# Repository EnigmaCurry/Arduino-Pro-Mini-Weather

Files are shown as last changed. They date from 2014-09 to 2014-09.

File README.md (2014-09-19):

Arduino Pro-Mini Enviromental Display Project
========================

This is an arduino project to build a miniature environment sensor
module to display temperature, barometric pressure, and humidity.

All files contained herein produced by
[R&TPreppers](https://www.youtube.com/channel/UCTNV_Oh5QAi1Is9r9Aw5bpw)
/ [njsharkracer](https://github.com/njsharkracer)

Arduino Pro Mini Weather Video (https://www.youtube.com/watch?v=pLE4Hpk1XHw)

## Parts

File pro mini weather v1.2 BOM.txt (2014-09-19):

| BT1        1.5V AA     AA Battery Holder
| C1         47uF        1210
| C2         10uF        0805
| C3         100nF       0805
| D1         DIODESCH    SOD-123
| L1         68uH        0805
| R1         4.7K        0805
| R2         4.7K        0805
| U1         NCP1402     SOT23-5
| U2         PRO_MINI    Sparkfun pro mini 5V 16Mhz
| U3         DHT22       Through Hole
| U4         BMP180      Custom Footprint
| U5         NOKIA_5110  Through Hole

If you want to order the boards directly through OSHPark:

https://oshpark.com/profiles/rtpreppers

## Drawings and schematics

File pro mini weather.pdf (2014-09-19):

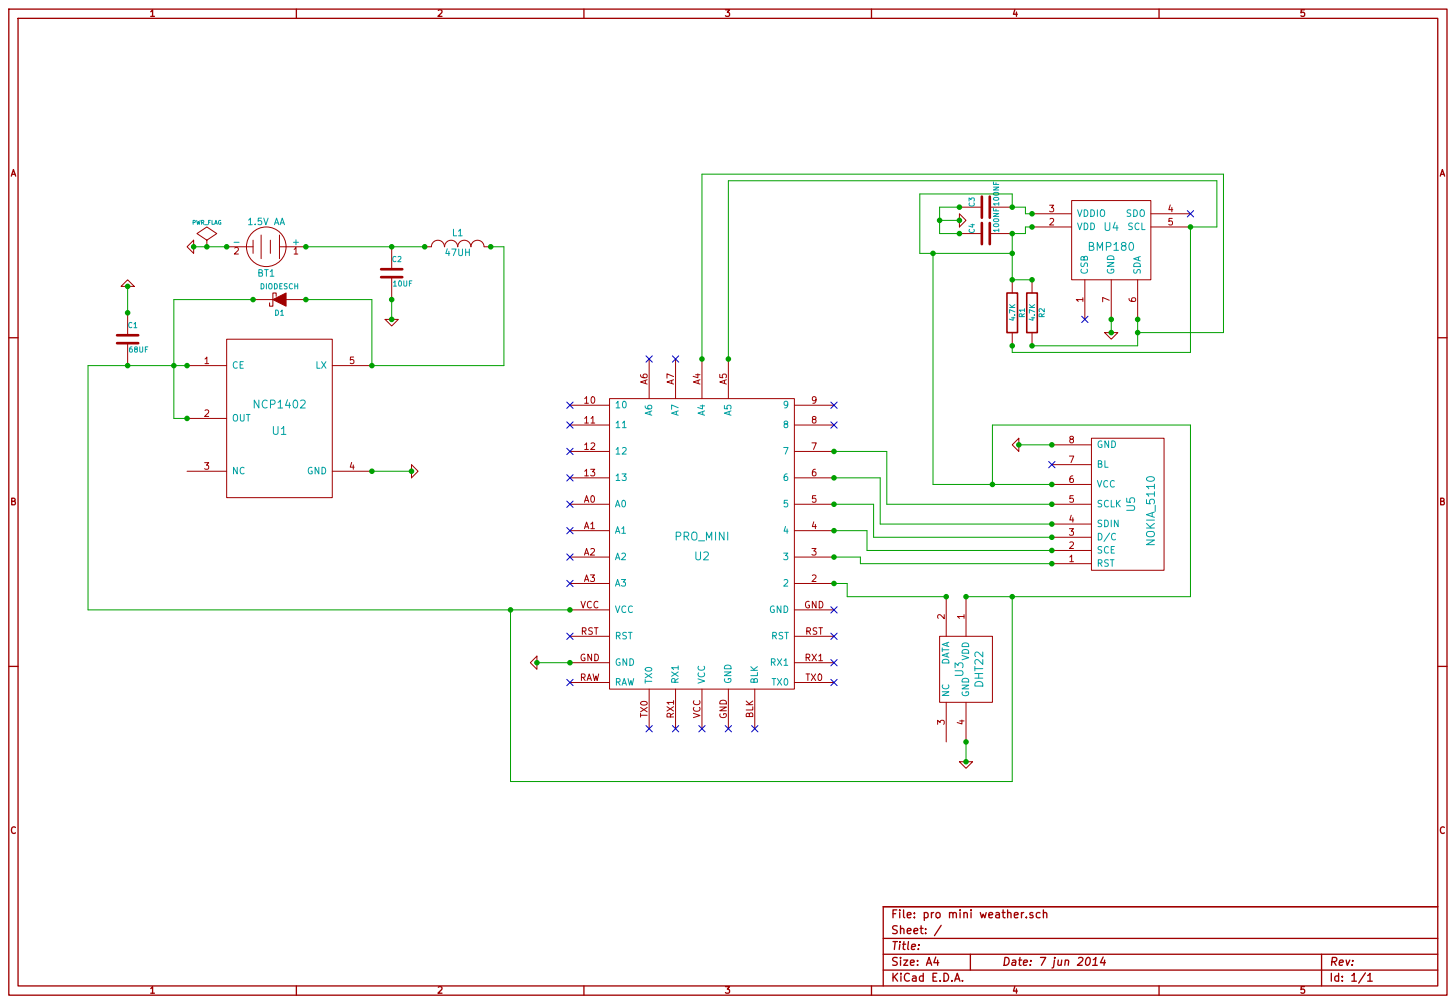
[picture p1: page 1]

Id: 1/1 Title: File: pro mini weather.sch

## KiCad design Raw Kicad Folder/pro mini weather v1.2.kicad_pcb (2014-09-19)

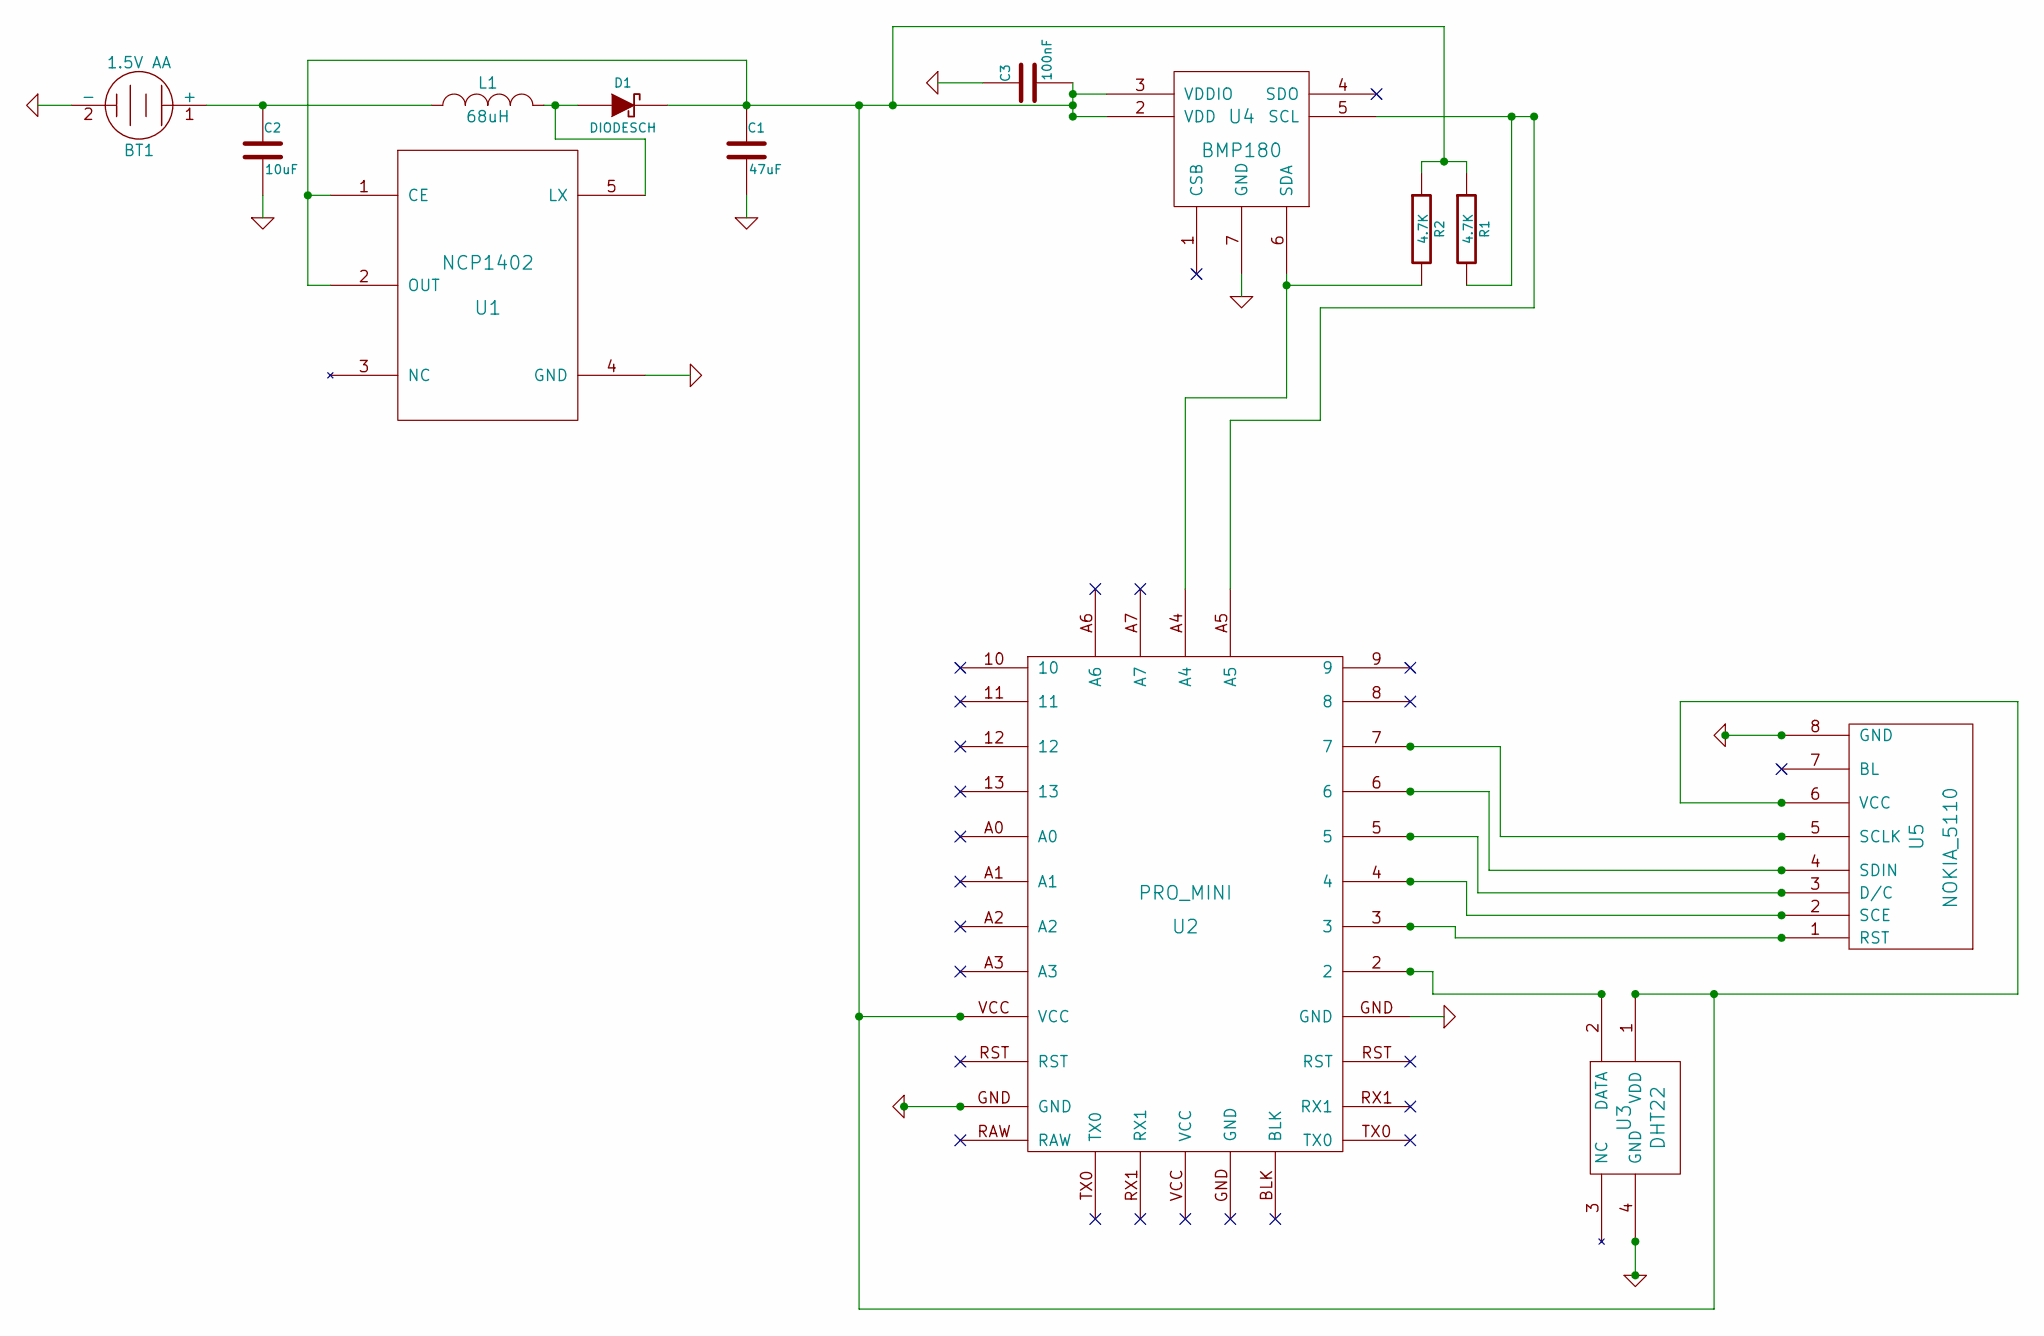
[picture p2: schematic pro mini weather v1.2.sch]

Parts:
BT1: 1.5V AA
C1: 47uF
C2: 10uF
C3: 100nF
D1: DIODESCH
L1: 68uH
R1, R2: 4.7K
U1: NCP1402
U2: PRO_MINI
U3: DHT22
U4: BMP180
U5: NOKIA_5110

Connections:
GND: BT1.2 (-), C1.2, C2.2, C3.1, U1.4 (GND), U2.GND, U3.4 (GND), U4.7 (GND), U5.8 (GND)
unnamed: D1.1 (A), L1.2, U1.5 (LX)
unnamed: R2.2, U2.A4, U4.6 (SDA)
unnamed: R1.2, U2.A5, U4.5 (SCL)
unnamed: C1.1, C3.2, D1.2 (K), R1.1, R2.1, U1.1 (CE), U1.2 (OUT), U2.VCC, U3.1 (VDD), U4.2 (VDD), U4.3 (VDDIO), U5.6 (VCC)
unnamed: U2.2, U3.2 (DATA)
unnamed: U2.3, U5.1 (RST)
unnamed: U2.5, U5.3 (D/C)
unnamed: U2.6, U5.4 (SDIN)
unnamed: U2.7, U5.5 (SCLK)
unnamed: U2.4, U5.2 (SCE)
unnamed: BT1.1 (+), C2.1, L1.1

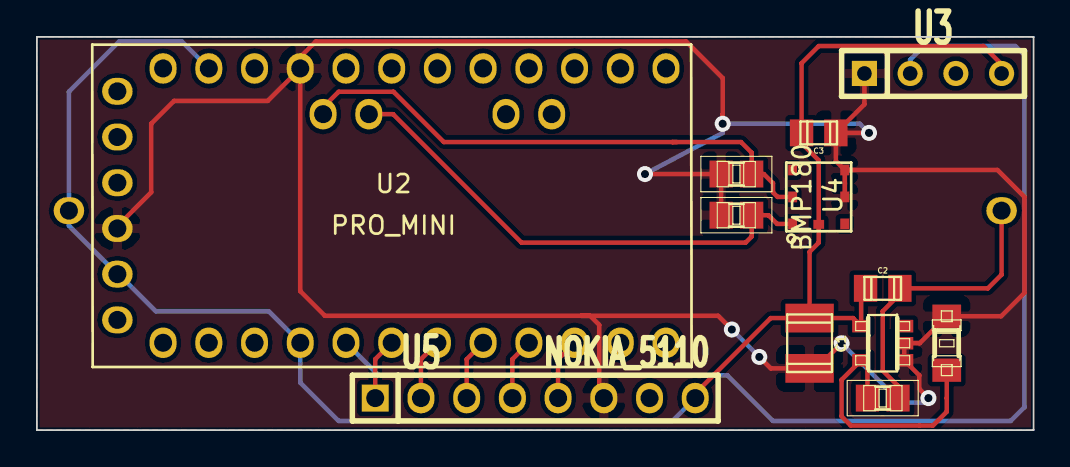
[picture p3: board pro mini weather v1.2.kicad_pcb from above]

Board: 2 copper layers, 55.4 x 21.8 mm, 13 parts (1 on the bottom side), 12 nets.

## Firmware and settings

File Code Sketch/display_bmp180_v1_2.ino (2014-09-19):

#include <SPI.h>
#include "Adafruit_GFX.h"
#include "Adafruit_PCD8544.h"
#include <SFE_BMP180.h>
#include <Wire.h>
#include "LowPower.h"
#include "DHT.h"
 
//GFX, DHT & PCD8544 can be found in adafruits github.
//SFE_BMP180 can be found on Sparkfun's github.


// Software SPI (slower updates, more flexible pin options):
// pin 7 - Serial clock out (SCLK)
// pin 6 - Serial data out (DIN)
// pin 5 - Data/Command select (D/C)
// pin 4 - LCD chip select (CS)
// pin 3 - LCD reset (RST)
Adafruit_PCD8544 display = Adafruit_PCD8544(7, 6, 5, 4, 3);

SFE_BMP180 pressure;

//#define ALTITUDE 15.0 //  Altitude at location
#define DHTPIN 2
#define DHTTYPE DHT22

DHT dht(DHTPIN, DHTTYPE);

void setup()   
{

Serial.begin(9600);

  // Initalize the BMP180 Sensor
  if (pressure.begin())

    dht.begin();
    display.begin();
  // init done

  // you can change the contrast around to adapt the display
  // for the best viewing!
  display.setContrast(57);
  display.clearDisplay();   // clears the screen and buffer

}


void loop() {

  // Reading temperature or humidity takes about 250 milliseconds!
  // Sensor readings may also be up to 2 seconds 'old' (its a very slow sensor)
  int h = dht.readHumidity();
  // Read temperature as Celsius
  int t = dht.readTemperature();
  // Read temperature as Fahrenheit
  int f = dht.readTemperature(true);
  
  // Compute heat index
  // Must send in temp in Fahrenheit!
  int hi = dht.computeHeatIndex(f, h);

  
  //  Display Names On Left Side Of Display And Horizontal Lines
  display.clearDisplay();
  display.setTextSize(1);
  display.setCursor(0,0);
  display.print("T");
  display.setCursor(6,3);
  display.print("E");
  display.setCursor(12,5);
  display.print("M");
  display.setCursor(18,7);
  display.print("P");
  display.setCursor(0,18);
  display.print("P");
  display.setCursor(6,20);
  display.print("R");
  display.setCursor(12,22);
  display.print("E");
  display.setCursor(18,24);
  display.print("S");
  display.setCursor(0,35);
  display.print("H");
  display.setCursor(7,37);
  display.print("U");
  display.setCursor(14,39);
  display.print("M");
  display.drawLine(0,15,84,15,1);
  display.drawLine(0,32,84,32,1);

  
  char status;
  double T,P,p0,a;

  // Loop here getting pressure readings every 10 seconds.
  // Start a temperature measurement:
  // If request is successful, the number of ms to wait is returned.
  // If request is unsuccessful, 0 is returned.

  status = pressure.startTemperature();
  if (status != 0)
  {
    // Wait for the measurement to complete:
    delay(status);

    // Retrieve the completed temperature measurement:
    // Note that the measurement is stored in the variable T.
    // Function returns 1 if successful, 0 if failure.

    status = pressure.getTemperature(T);
    if (status != 0)
    {

      // Print out the measurement:
      display.setCursor(24,0);
      display.setTextSize(2);
      display.print((9.0/5.0)*T+32.0,0);
      display.print("'F");

      // Start a pressure measurement:
      // The parameter is the oversampling setting, from 0 to 3 (highest res, longest wait).
      // If request is successful, the number of ms to wait is returned.
      // If request is unsuccessful, 0 is returned.

      status = pressure.startPressure(3);
      if (status != 0)
      {
        // Wait for the measurement to complete:
        delay(status);

        // Retrieve the completed pressure measurement:
        // Note that the measurement is stored in the variable P.
        // Note also that the function requires the previous temperature measurement (T).
        // (If temperature is stable, you can do one temperature measurement for a number of pressure measurements.)
        // Function returns 1 if successful, 0 if failure.

        status = pressure.getPressure(P,T);
        if (status != 0)
        {
          // Print out the measurement:
          display.setCursor(24,17);
          display.print(P*0.0295333727,2);
          display.setCursor(24,34); 
          display.print(h+2);
          display.print("%");
          display.setTextSize(1);
          display.setCursor(60,34);
          display.print("H.I.");
          display.setCursor(60,41);
          display.print(hi);
          display.print("F");
          display.display();
        }
        else Serial.println("error retrieving pressure measurement\n");
      }
      else Serial.println("error starting pressure measurement\n");
    }
    else Serial.println("error retrieving temperature measurement\n");
  }
  else Serial.println("error starting temperature measurement\n");

    // sleep mode code

    // Enter power down state for 8 s with ADC and BOD module disabled
    LowPower.powerDown(SLEEP_8S, ADC_OFF, BOD_OFF);  

}
